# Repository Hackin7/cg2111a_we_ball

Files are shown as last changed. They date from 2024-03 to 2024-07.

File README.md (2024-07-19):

# cg2111a_we_ball

our robot will move as smoothly as a ball. Code here is modified from the template code with our various additions. More information about those additions can be found in our reports in `reports/`

# `main` branch

## PC - Client Code

Code found in `client_pc/tls-client-lib`. Compile using `compile.sh` and run `tls-alex-client <IP> <PORT>`.

# `main-rpi` branch

Repository should be put in `/home/pi/Documents/cg2111a_we_ball/`

## Arduino - Firmware Code

Code can be found in `/arduino/Alex`

For the `.ino` files, the compiler first loads the principal file (the one with the same name as the folder)
and then loads the others in alphabetical order. Concept behind multiple files can be found here: 
https://forum.arduino.cc/t/correct-way-to-include-multiple-files/507705/3 

Order of imports would be as such (think of it as combining into 1 big `.ino` file in this order)

```
Alex.ino
0_motors.ino
...
6_robotlib.ino
```

To get it to compile make sure to import `serialize.zip` as an arduino library first.

The compile and upload script for the firmware is in `arduino/upload.sh`

## RPi - Server Code

Can run  `server_rpi/start.sh`

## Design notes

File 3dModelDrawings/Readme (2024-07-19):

Just a compilation of the chassis 3d models

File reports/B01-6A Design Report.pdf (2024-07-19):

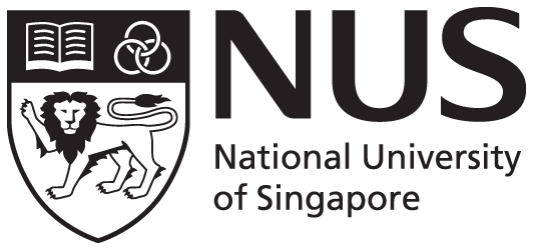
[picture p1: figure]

### CG2111A Engineering Principle and Practice II

Semester 2 2022/2023

## “Alex to the Rescue”

# Design Report Team: B01-6A

Name | Student # | Sub-Team | Role
Jonathan Ong | A0283070L | Software | Colour Detection/ Hardware Design
Quan Teng Wai | A0281416H | Software | LIDAR Implementation
Piraveen Alexander | A0273022U | Software | Robot Movement
Chan Zun Mun Terence | A0282142M | Hardware | Circuit Design
1 | Page

Section 1 System Functionalities

Our Alex Robot is designed to emulate the functionalities of a search and rescue robotic vehicle. It would be wirelessly controlled by operators to move in a simulated environment.

Alex will include a Raspberry Pi and an Arduino Mega. The Raspberry Pi has a Master Control Program to communicate with Arduino via UART. The Arduino is then able to control the motors and return information from the ultrasonic sensors to the Raspberry Pi, for Alex to gather data and navigate through the Course. At the same time, the Raspberry Pi receives data from the LIDAR to map out the environment.

The operators would use a Laptop. It communicates with the Raspberry Pi to remotely control the robot, using SSH for controlling movement & sensors, and ROS Networking for retrieving SLAM data.

Simulated Environment
Our Alex would be used in a room with various objects, such as tables, chairs and boxes. We would pilot Alex to find at least 2 victims in a 6-minute window. These victims are green (healthy but trapped), or red (injured and trapped).

Main Functionalities:
1. Move orthogonally (Forwards, Backwards, Left Turn, Right Turn)
2. Identify objects within the test area using the Colour Sensor
3. Map out the test area with the help of the LIDAR and SLAM
4. Enough battery life to minimally last the entire test duration ( ~15min )
5. Be remote-controlled by a teleoperator

Additional Functionalities:
1. Detect the colour of any nearby object.
2. Alex is able to be “cool”
a. It would have Ultrasonic Sensors to detect the distance of the front/ back/ side of the robot to the obstacles
b. It would have a face (our teammate’s)

Section 2 Review of State of the Art

There are many different designs in the modern search and rescue robotic arsenal. Here are 2 that interested us.
1. Earthshaker, winner of the first Advanced Technology and Engineering Challenge (A-TEC) championships.

Teleoperation was achieved with 3 different communication methods between the Operator PC and the On-board computer (NUC).
Using a 1.8G MIMO mesh radio, 2xAT9S, STM32 Control board and a 4G/5G router.
Software enables automated switching

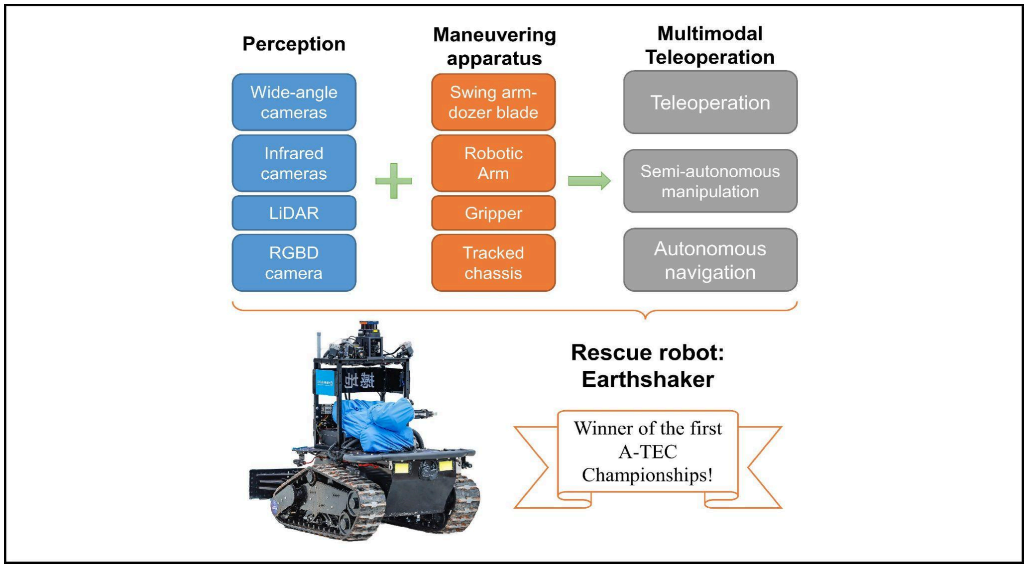
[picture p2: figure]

between communication modes depending on connection quality/ range.

Strengths | Weaknesses
- Chassis and components minimally IP64 water resistant, able to handle wet environments ● Dozer Blade allows it to push obstacles under 75kg away ● Multiple communication methods, from 2.4Ghz direct communication to 1.8 GHz MIMO-mesh radios to suit a different ranges and conditions | ● Excessive size limited flexibility of movement ● Lacking in gripping power for modified robot arm, unable to manipulate heavier loads. ● Battery life of 3h ● Cumbersome body slower at navigating stairs
2. Vapor 55 Drone, used in spotting sharks, dropping life rafts and medical equipment in Australia, originally designed to deliver blood and supplies to wounded soldiers.

Hardware:
Trillium HD-25 Optical sensor (Camera) Lidar/ PPK Mapping Options

Software:
Advanced Flight Control System (FCS) [inclusive of autopilot]
Automatic Autorotation, smart auto-home functions

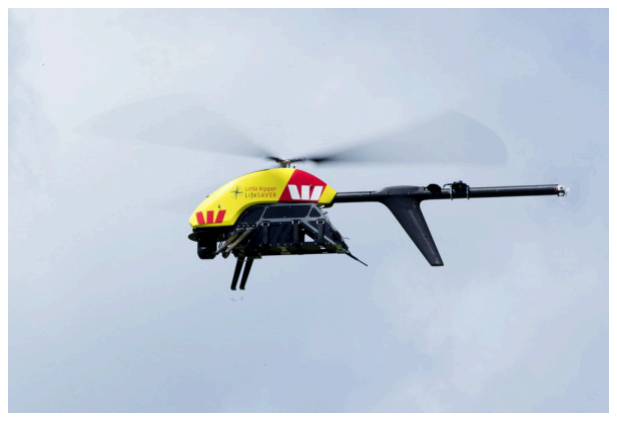
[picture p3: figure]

Strengths | Weaknesses
- Modular radio options (Common Radio Interface connector) ● Flexible Payload - rail design enables many different kinds of payloads to be equipped ● Aerial - Unrestricted by Terrain | ● Battery life of 1h ● Environmental Operational Limits from -17C to 49C, unable to be used in extreme temperatures ● Comparatively low Usable payload of 4.5kg compared to ground options

(Rubble/ Ocean)

Section 3 System Architecture High Level Components

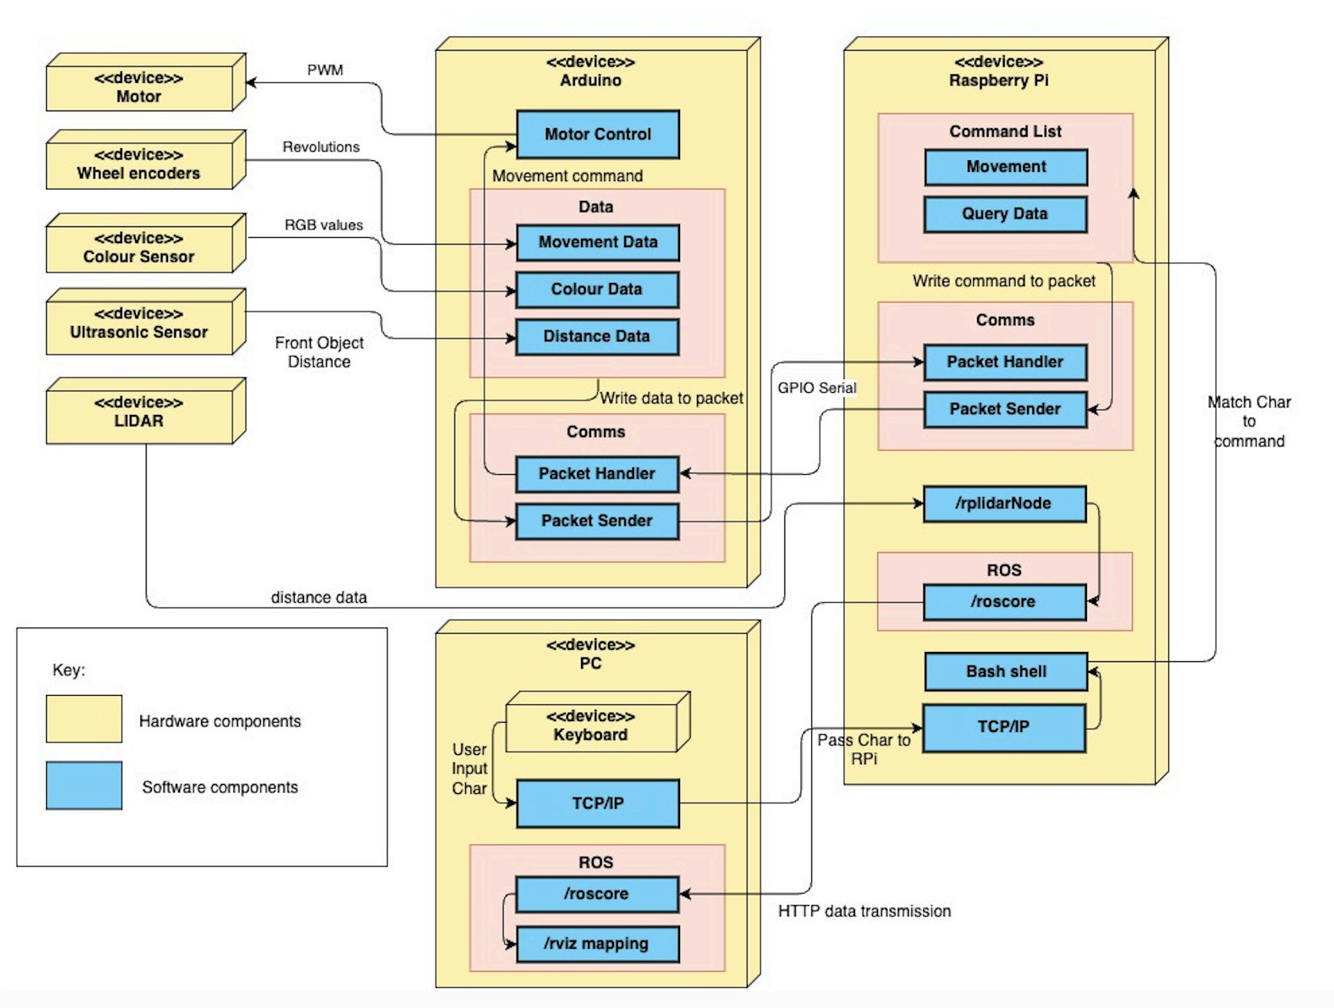
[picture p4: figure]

Schematic (Subject to Changes)

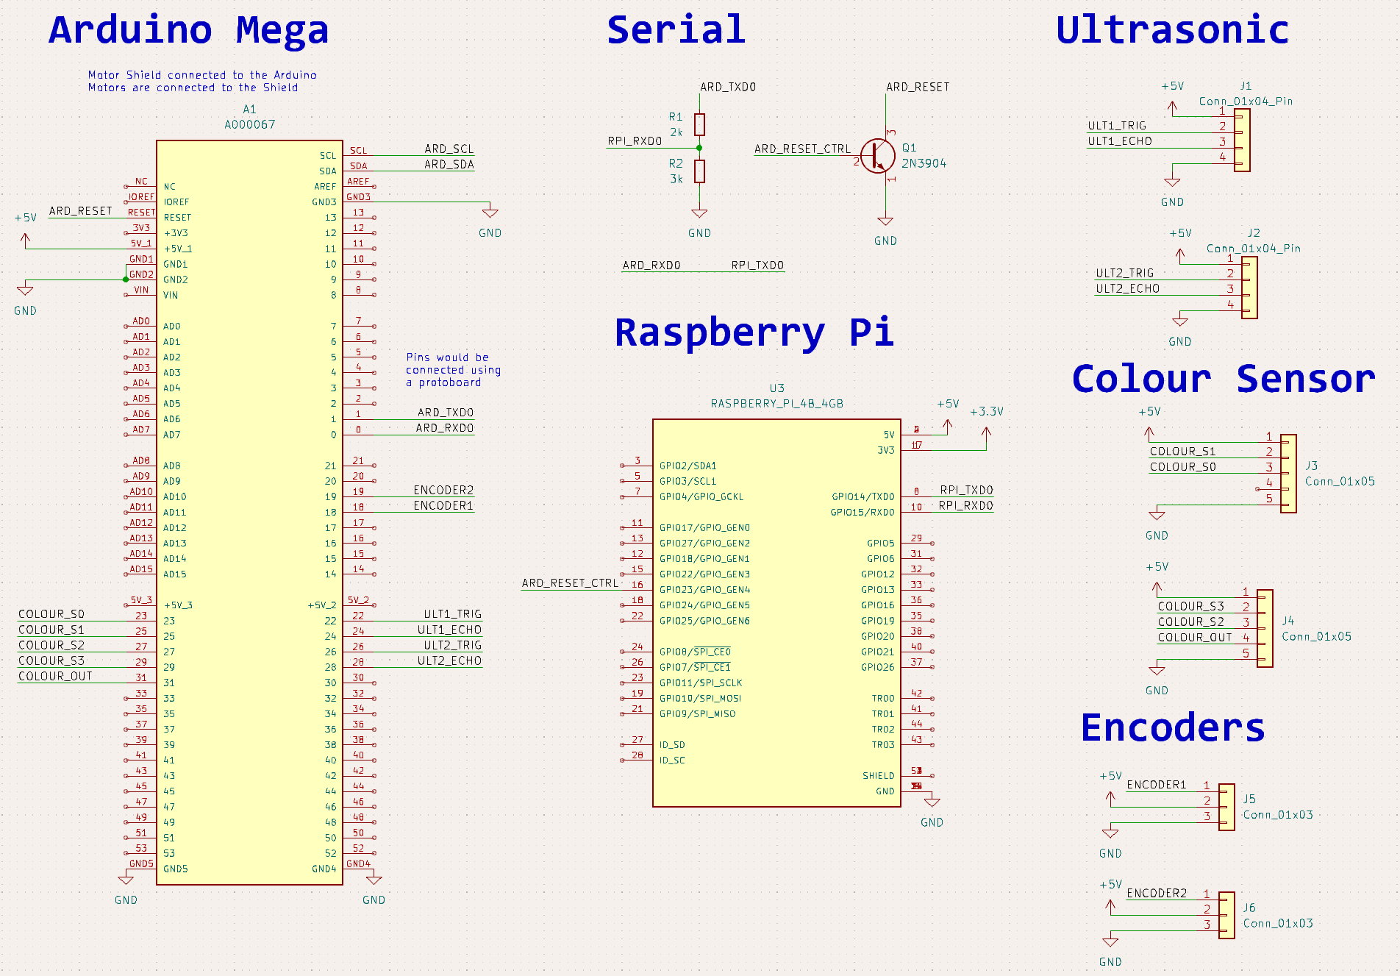
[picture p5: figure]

Electronics will be connected through wires and a protoboard for ease of assembly, and ease of access to the pins.

1. LIDAR would be connected to the Raspberry Pi via USB
2. Motors would be connected to the Motor Shield, and the Motor Shield would be connected to the Arduino. The Protoboard goes between the Shield and the Arduino
3. The RPi would be powered by a USB Power Bank, while the Motors and Motor Shield will be powered by 4 1.5V AA batteries

Section 4 Component Design

High-Level Algorithm Steps:
1. Initialise communication between Arduino, Pi and PC
2. Generate map with Hector SLAM
3. Receive tele-operator commands
4. Carry out commands
5. Repeat steps 3 and 4 until navigation is over

Further Breakdown
Step 1: Initialise communication between Arduino, Pi and PC
a. Pi - Arduino Mega Communication
i. Pi opens a Serial Connection to the Arduino Mega
ii. | Pi creates, serializes and sends a Hello Packet to the Arduino
iii. | Arduino initialises the Serial port and responds to the Hello Packet by sending
| back an OK packet
b. Pi - Laptop Communications
i. Pi opens a TCP/IP server and binds to a port
ii. | The laptop connects to the server over the same WiFi Network
iii. | With the help of OpenSSL, the Laptop authenticates with the Pi and
| communicates securely.
c. Others
i. ROS is Started on the Pi, which the Laptop connects to through ROS
| networking
ii. | The Laptop can SSH/ VNC into the Pi
Step 2: Generate map with Hector SLAM
a. Pi gets distance data from LIDAR and odometry data from Arduino
b. Pi sends occupancy data to PC through ROS
c. PC generates map with Hector SLAM with occupancy data
Step 3: Receive tele-operator commands
a. After reviewing map, tele-operator sends commands:
| Movement Commands
W | A | S | D | X
Forward (increase linear speed in positive direction) | Rotate Left (increase angular speed in negative direction) | Stop | Rotate Right (increase angular speed in positive direction) | Reverse (increase linear speed in negative direction)

Additional Commands

C V

Sense colour | Get ultrasonic sensor distance
b. PC sends commands to Pi through TCP/IP through the packet sender
c. Pi handles packets and sends commands to Arduino

Step 4: Carry out commands
a. Depending on the command, Arduino does the following:
Command Type | Movement | Colour | Ultrasonic Sensor
Execution | sends PWM signals to motors | triggers colour sensor | triggers ultrasonic sensor
Return | odometry data calculated from wheel encoders | colour determined from RGB values | returns ultrasonic distance
b. Pi receives the data from the Arduino and LIDAR and handles it as follows:
Arduino | LIDAR
Colour | Ultrasonic Sensor | Map data
Returns data to PC through TCP/IP | | Publishes to ROS topic
c. PC receives data and does the following:
TCP/IP data | ROS data
displays to tele-operator | updates Hector SLAM map and displays to tele-operator
Step 5: Repeat steps 3 and 4 until navigation is over
a. Tele-operator identifies when navigation is over and sends command to end program

Serial Communications
Raspberry Pi
1. Pi opens a Serial Connection to the Arduino Mega
a. Baud Rate 9600 bps, 8N1 Frame format
2. Pi creates a receiver thread to receive packets from Arduino
a. The packet is deserialized into a TPacket packet, and TResult result
b. It checks TResult for the status of the packet
i. If the Packet received is OK, it handles it (such as in Further Breakdown Step 4b)
ii. | Else, it displays the error, be it an unknown error, bad magic number,
| or bad checksum, and sends it to the laptop
3. Pi Sends command packets to the Arduino depending on the teleoperator commands
a. It creates a TPacket commandPacket
b. Configures the packet command and parameters c. Serialises it into a TComms packet
d. Sends it over to the Arduino through UART

Arduino Mega
4. Arduino Mega sets up Serial port
a. Baud Rate 9600 bps, 8N1 Frame format
5. Arduino polls for serial data
a. It reads the Serial data & stores it in a buffer
b. The data is then deserialized into a TPacket packet and TResult result
c. It checks TResult result for the status of the packet
i. If the Packet received is OK,
1. it handles it (such as in Further Breakdown Step 4a),
2. It sends an OK packet to the Pi, or a packet with the required information depending on the command.
ii. | Else, it sends an error back to the Pi, be it an unknown error, bad magic
| number, or bad checksum
iii. | The creation of packets is similar to how the Raspberry Pi does it

Distance Sensing Algorithm
1. Set the trigger pin to high for 10 microseconds to send the pulse
2. Reads the Echo Pin and gets the length of the pulse on the echo pin
3. Convert the period to the distance between the ultrasonic sensor to the wall
a. Distance = (Speed of Sound × Time taken) / 2
4. Sends a packet with the distance information to the RPi

Color Sensing Algorithm
1. Set Trigger pin to HIGH to trigger Colour Sensing
2. Colour Sensor Module to cycle between RGB lighting
a. Individually Toggle Each of the colour LED Pins to HIGH, delay, then LOW.
b. Read the respective frequencies from the colour sensor during each colour phase
3. With reference to the ROYGBIV table that has the respective range of frequencies for each colour, determine the colour of the object in front of the Color Sensor.
4. Relay information to the RPi, which is then sent to the laptop.

Section 5 Project Plan

Week | Hardware | Software
8 & 9 | Assembling Alex & Electronics | 1. Communications between Arduino & Raspberry Pi 2. Configure Motor Encoders 3. Set up Secure Communications (TLS)
10 | 1. Finalise Electronics Schematic & Wiring the Protoboard 2. Debugging the Protoboard & Electronics | Setting up the Raspberry Pi 1. SSH, VNC remote protocols for Debugging 2. Code Repository & Layout
11 | 1. Mounting of Components 2. Designing and 3D printing required structures | 1. Setting up Hector SLAM 2. Setting up Colour Sensor & Colour Detection Algorithm 3. Test Basic Movement
12 | 1. Adjusting Mounts | 1. Setting up Ultrasonic Sensor 2. Calibration of Motors, Ultrasonic Sensors and Colour Sensors
13 | 1. Final Calibration & Further improvements based on trial run 2. Project Runs
Reading Week | Final Design Report

References

1. Zhang Y, Li Y X, Zhang H F, et al.
Earthshaker: A mobile rescue robot for emergencies and disasters through teleoperation and autonomous navigation.
JUSTC, 2023, 53(1): 4 doi: 10.52396/JUSTC-2022-0066
2. Avinc (n.d.) Product catalog. Retrieved March 28, 2024, from https://www.avinc.com/images/uploads/product_docs/ProductCatalog.pdf
3. Avnic (August 30, 2019). Vapor55 Datasheet. Retrieved March 28, 2024, from, https://www.avinc.com/images/uploads/product_docs/VAPOR55_datasheet_0830201 9.pdf (https://www.avinc.com/images/uploads/product_docs/VAPOR55_datasheet_08302019.pdf)
4. Little Ripper (n.d.) Our Amazingly Awesome & Proven UAV Fleet: Westpac Lifesaver Series. Retrieved March 28, 2024, from,
https://littleripper.com/our-fleet/

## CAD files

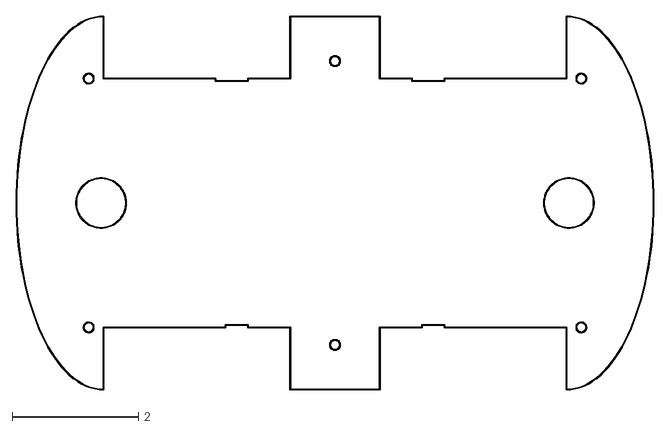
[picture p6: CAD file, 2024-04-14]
hardware/cg2111a_robot_kicad/cg2111a_robot-Edge_Cuts.dxf
10.1 x 5.92

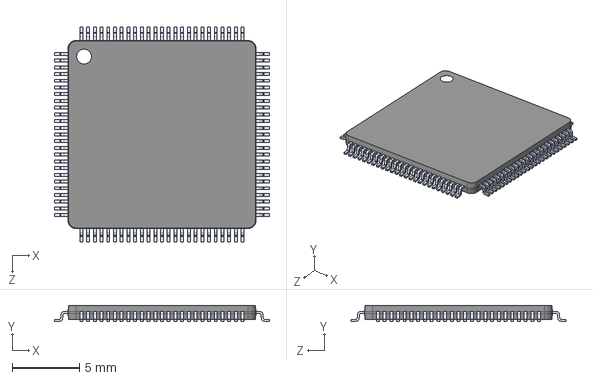
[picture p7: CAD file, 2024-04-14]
hardware/cg2111a_robot_kicad/footprints/3d_models/ATMEGA2560-16AU.step
16.0 x 1.20 x 16.0 mm

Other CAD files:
3dModelDrawings/002 v2.f3d
3dModelDrawings/Back Board v1.f3d
3dModelDrawings/Nozzle v1.f3d
3dModelDrawings/Potoboard holder v5.f3d
3dModelDrawings/Side Plate v1.f3d
3dModelDrawings/TANK v2.f3z

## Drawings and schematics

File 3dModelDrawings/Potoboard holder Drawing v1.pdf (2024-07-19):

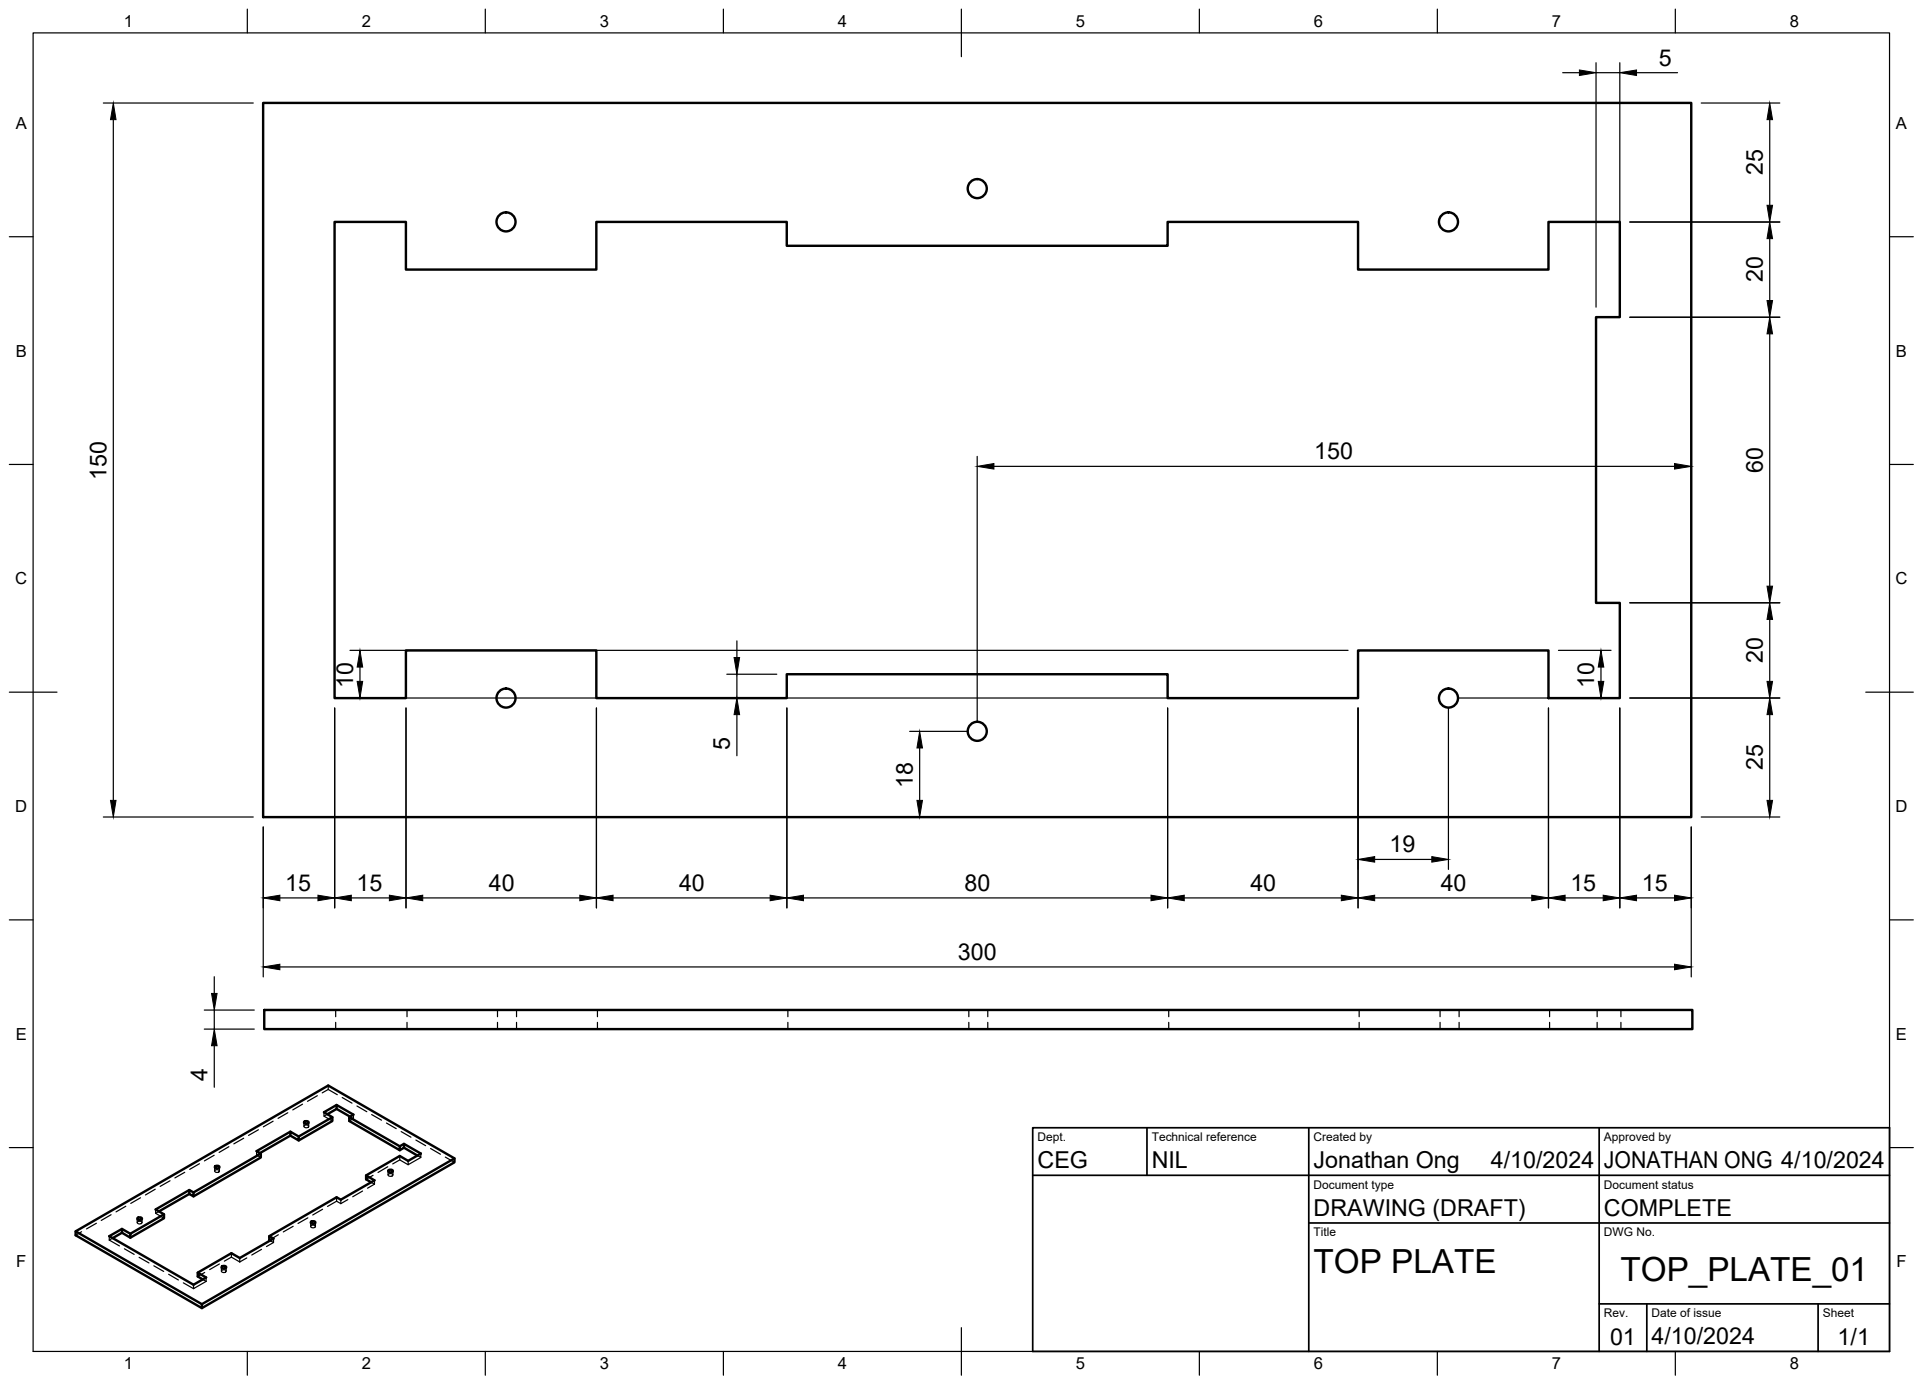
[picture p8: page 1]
Title; DWG No.; Rev.; Date of issue; Sheet; TOP PLATE; TOP_PLATE_01; CEG; NIL; Jonathan Ong; JONATHAN ONG 150

Dept. | Technical reference | Created by 4/10/2024 | Approved by 4/10/2024

Document type DRAWING (DRAFT) | Document status COMPLETE

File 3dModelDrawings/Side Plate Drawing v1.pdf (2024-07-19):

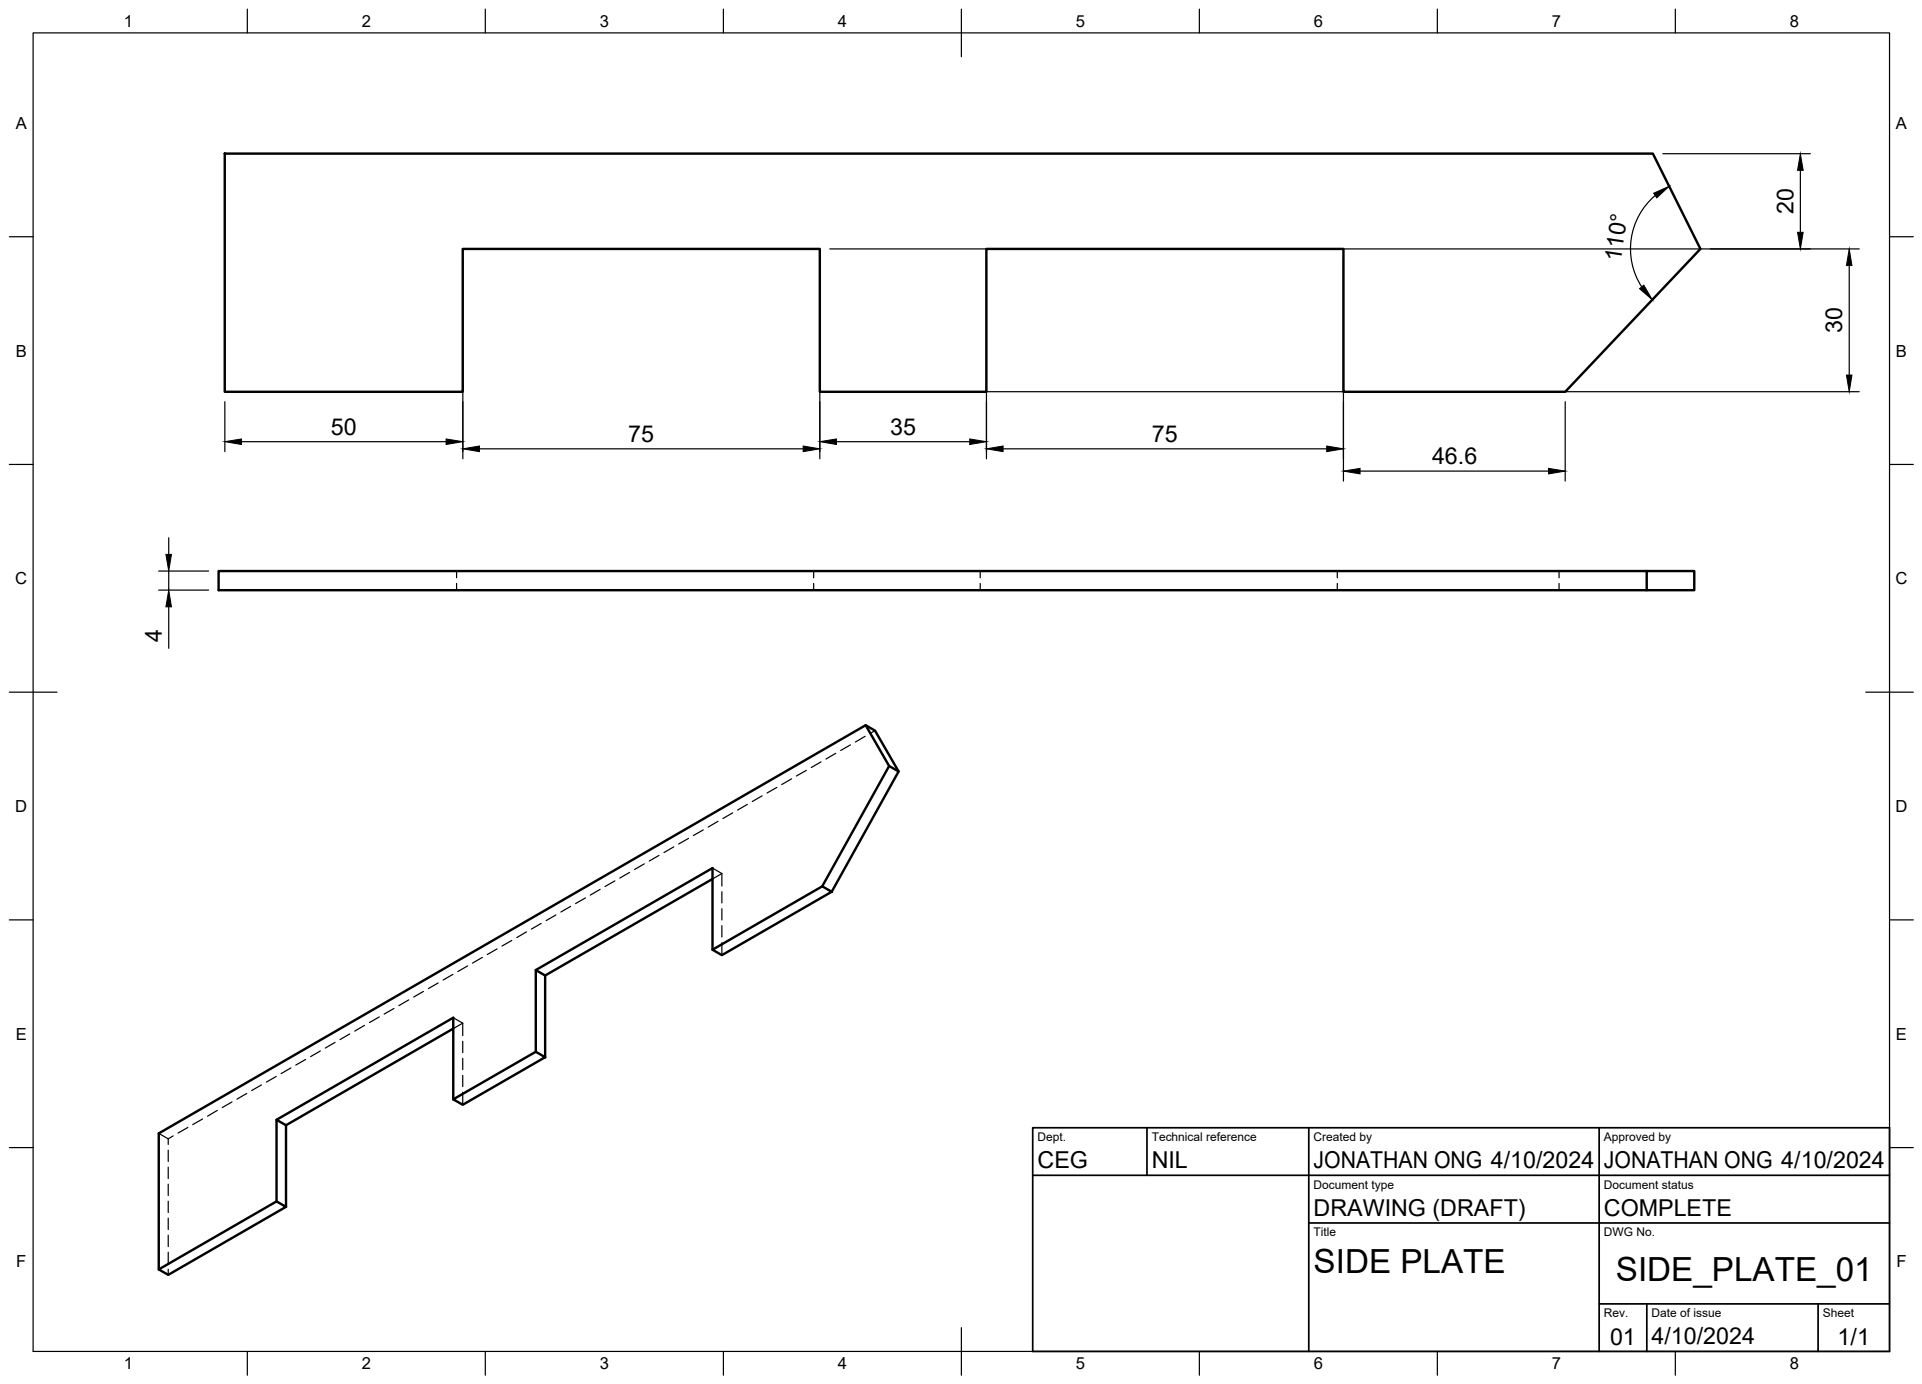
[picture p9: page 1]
Title; DWG No.; Rev.; Date of issue; Sheet; SIDE PLATE; SIDE_PLATE_01

Dept. CEG | Technical reference NIL | Created by JONATHAN ONG 4/10/2024 | Approved by JONATHAN ONG 4/10/2024

Document type DRAWING (DRAFT) | Document status COMPLETE

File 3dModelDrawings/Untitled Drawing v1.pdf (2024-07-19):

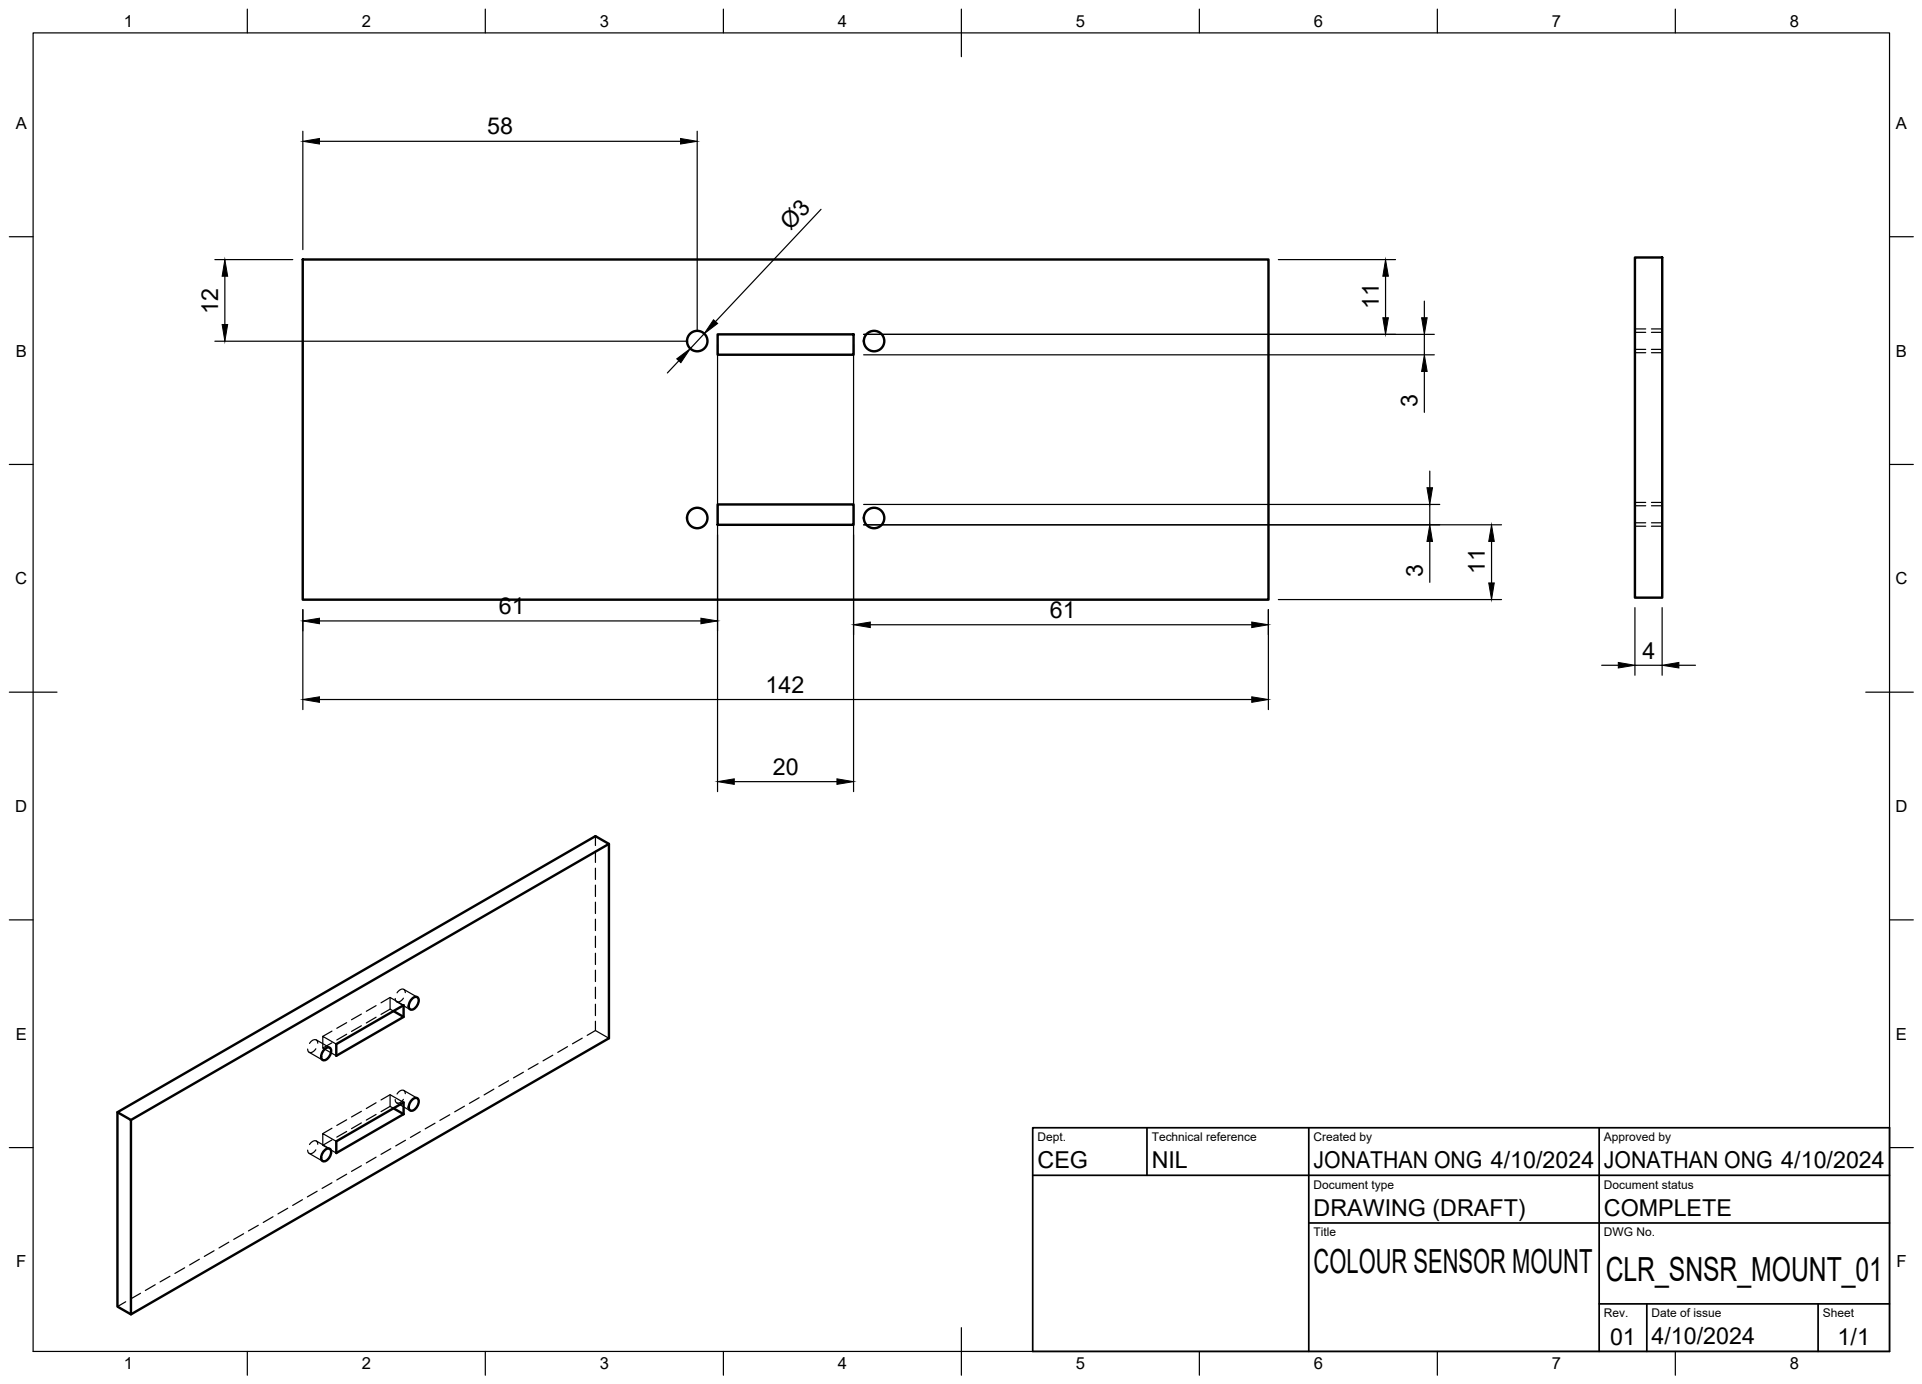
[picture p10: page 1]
Title; DWG No.; Rev.; Date of issue; Sheet; COLOUR SENSOR MOUNT; CLR_SNSR_MOUNT_01

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

Document type DRAWING (DRAFT) | Document status COMPLETE

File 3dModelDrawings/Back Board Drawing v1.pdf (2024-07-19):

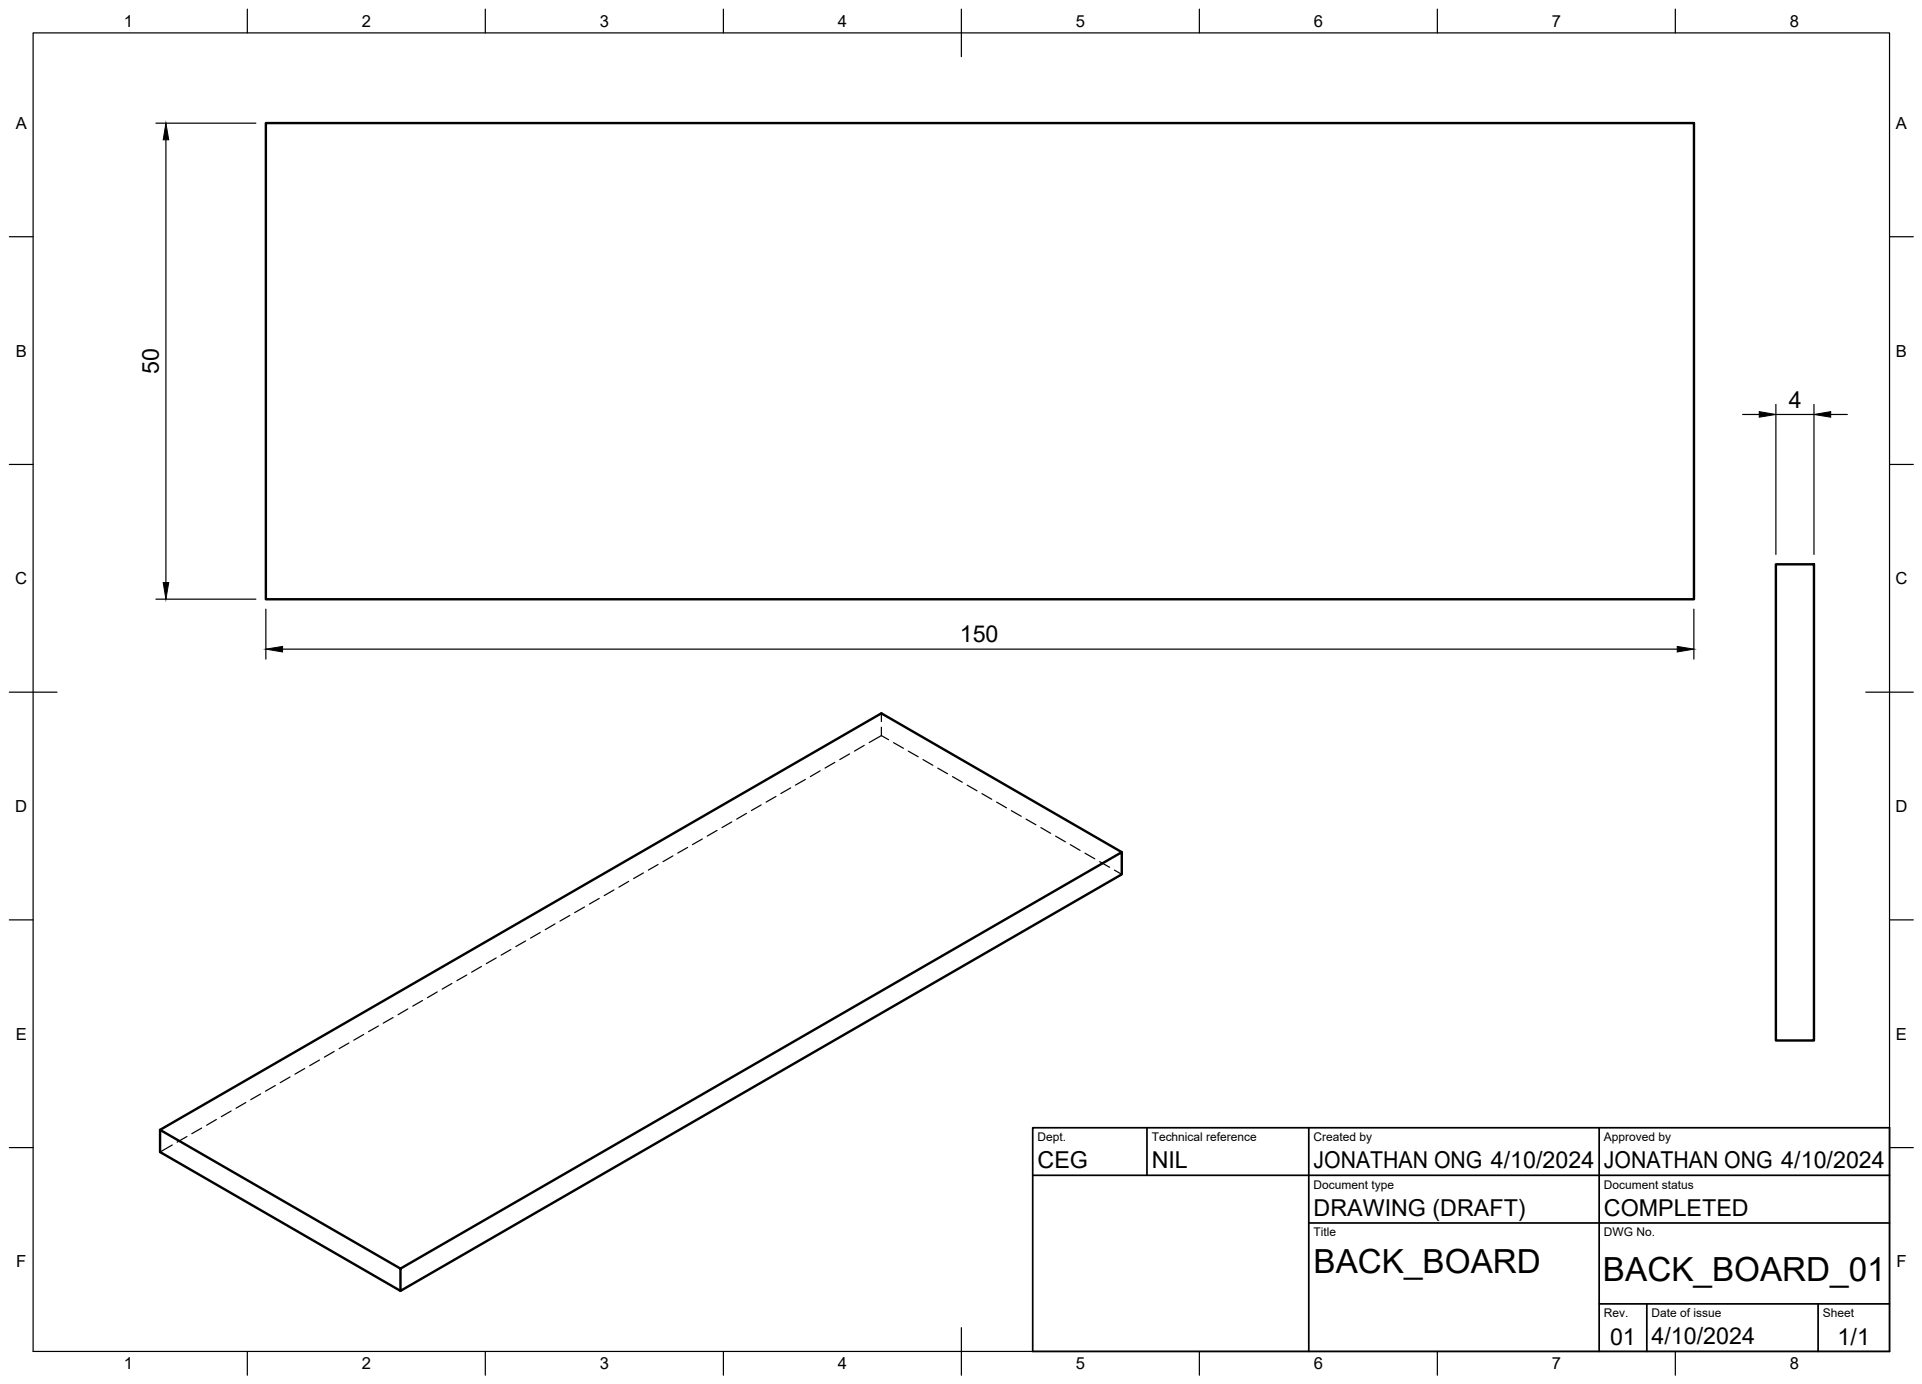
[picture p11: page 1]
Title; DWG No.; Rev.; Date of issue; Sheet; CEG; NIL; JONATHAN ONG; JONATHAN ONG 50

Dept. | Technical reference | Created by 4/10/2024 | Approved by 4/10/2024

Document type DRAWING (DRAFT) | Document status COMPLETED

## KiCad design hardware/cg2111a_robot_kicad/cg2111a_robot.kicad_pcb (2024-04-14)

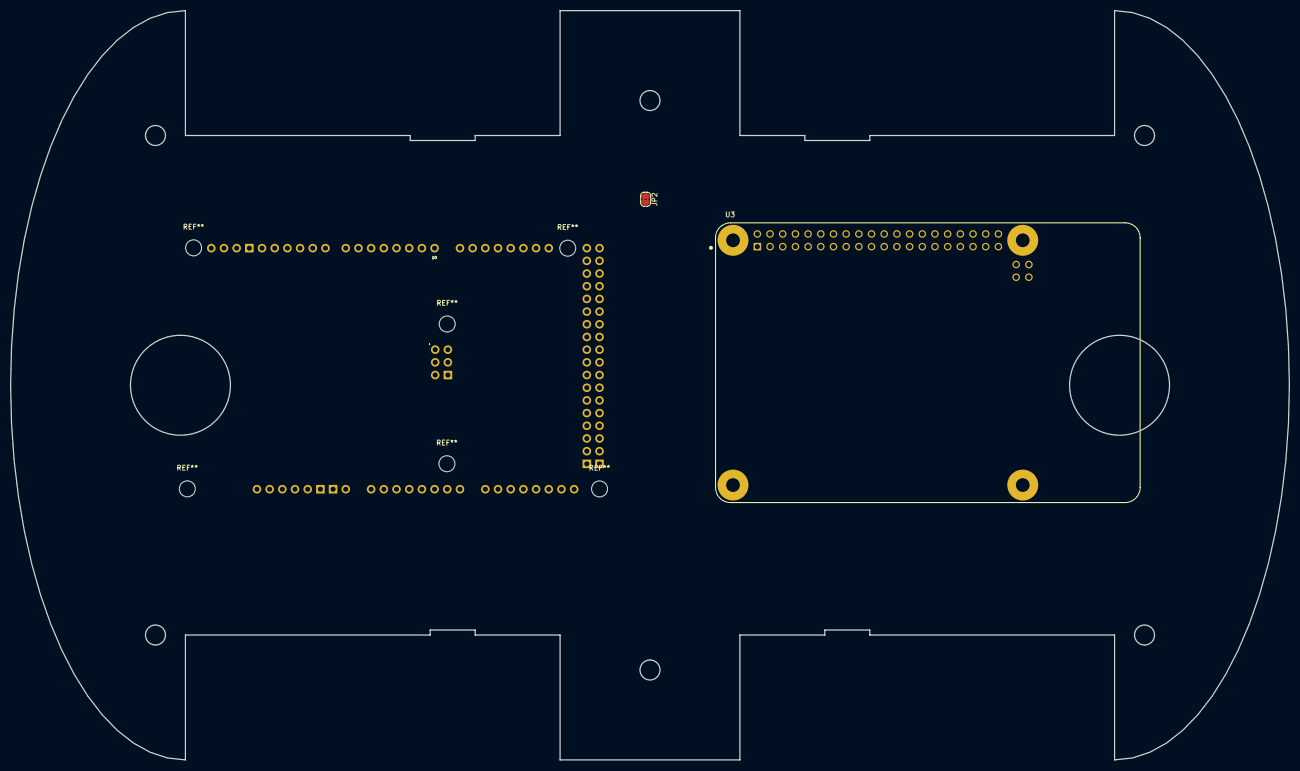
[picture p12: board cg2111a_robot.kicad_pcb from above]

Board: 2 copper layers, 256.0 x 150.0 mm, 3 parts (0 on the bottom side), 4 nets, no tracks yet.

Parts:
JP2: SolderJumper_2_Bridged; SolderJumper-2_P1.3mm_Bridged2Bar_RoundedPad1.0x1.5mm
U3: RASPBERRY_PI_4B_4GB; MODULE_RASPBERRY_PI_4B_4GB
XA1: Arduino_Mega2560_Shield

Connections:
GND: U3.6 (GND), U3.9 (GND), U3.14 (GND), U3.20 (GND), U3.25 (GND), U3.30 (GND), U3.34 (GND), U3.39 (GND)
unnamed: U3.2 (5V), U3.4 (5V)
unnamed: U3.S1 (SHIELD), U3.S2 (SHIELD), U3.S3 (SHIELD), U3.S4 (SHIELD)
VCC: JP2.1 (A), U3.1 (3V3), U3.17 (3V3)

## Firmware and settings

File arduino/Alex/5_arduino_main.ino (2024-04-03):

void setup() {
  // put your setup code here, to run once:
  alexDiagonal = sqrt((ALEX_LENGTH * ALEX_LENGTH) + (ALEX_BREADTH *
    ALEX_BREADTH));
  alexCirc = PI * alexDiagonal;
  
  cli();
  setupEINT();
  setupSerial();
  startSerial();
  enablePullups();
  initializeState();
  sei();
}



void loop() {

  //motorDebug();
  // put your main code here, to run repeatedly:
  TPacket recvPacket; // This holds commands from the Pi

  TResult result = readPacket(&recvPacket);
  
  if(result == PACKET_OK){
      handleCommand(&recvPacket);
  }else{
    if(result == PACKET_BAD)
    {
      sendBadPacket();
    }
    else if(result == PACKET_CHECKSUM_BAD)
    {
      sendBadChecksum();
    } 
  }

  if(deltaDist > 0)
  {
    if(dir==FORWARD)
    {
      if(forwardDist > newDist)
      {
        deltaDist=0;
        newDist=0;
        stop();
      }
    } else if (dir == BACKWARD)
    {
      if(reverseDist > newDist)
      {
      deltaDist=0;
      newDist=0;
      stop();
      }
    } else if(dir == STOP)
    {
      deltaDist=0;
      newDist=0;
      stop();
    }
  }
    
  if (deltaTicks > 0) {
    if (dir == LEFT) {
      if (leftReverseTicksTurns >= targetTicks){
        dbprintf("reset1: %d %d", leftReverseTicksTurns, targetTicks, "\n");
        deltaTicks = 0;
        targetTicks = 0;
        stop();
      }
    } else if (dir == RIGHT) {
      if (rightReverseTicksTurns >= targetTicks){
        dbprintf("reset2: %d %d", rightReverseTicksTurns, targetTicks, "\n");
        deltaTicks = 0;
        targetTicks = 0;
        stop();
      } 
    } else if (dir == STOP) {
        dbprintf("reset3: %d", targetTicks, "\n");
      deltaTicks = 0;
      targetTicks = 0;
      stop();
    } 
  }    
      
}

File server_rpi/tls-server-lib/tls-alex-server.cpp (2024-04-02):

#include "make_tls_server.h"
#include "tls_common_lib.h"
#include "netconstants.h"
#include "constants.h"
#include "packet.h"
#include "serial.h"
#include "serialize.h"

/* TODO: Set PORT_NAME to the port name of your Arduino */
#define PORT_NAME			"/dev/ttyS0"
/* END TODO */

// Check and ensure that this baud rate is the same
// as what is used in Alex.ino
#define BAUD_RATE			B9600

// TLS Port Number
#define SERVER_PORT			5001

/* TODO: #define constants for the  filenames for Alex's private key, certificate, CA certificate name,
        and the Common Name for your laptop */


#define PORTNUM 5001
#define KEY_FNAME   "keys/alex.key"
#define CERT_FNAME  "keys/alex.crt"
#define CA_CERT_FNAME   "keys/signing.pem"
#define CLIENT_NAME     "laptop.cg2111a.we.ball.com"
/* END TODO */

// Our network buffer consists of 1 byte of packet type, and 128 bytes of data
#define BUF_LEN				129

// This variable shows whether a network connection is active
// We will also use this variable to prevent the server from serving
// more than one connection, to keep connection management simple.

static volatile int networkActive;

// This variable is used by sendNetworkData to send back responses
// to the TLS connection.  It is sent by handleNetworkData

static void *tls_conn = NULL;

/*

	Alex Serial Routines to the Arduino

	*/

// Prototype for sendNetworkData
void sendNetworkData(const char *, int);

void handleErrorResponse(TPacket *packet)
{
	printf("UART ERROR: %d\n", packet->command);
	char buffer[2];
	buffer[0] = NET_ERROR_PACKET;
	buffer[1] = packet->command;
	sendNetworkData(buffer, sizeof(buffer));
}

void handleMessage(TPacket *packet)
{
	char data[33];
	printf("UART MESSAGE PACKET: %s\n", packet->data);
	data[0] = NET_MESSAGE_PACKET;
	memcpy(&data[1], packet->data, sizeof(packet->data));
	sendNetworkData(data, sizeof(data));
}

void handleStatus(TPacket *packet)
{
	char data[65];
	printf("UART STATUS PACKET\n");
	data[0] = NET_STATUS_PACKET;
	memcpy(&data[1], packet->params, sizeof(packet->params));
	sendNetworkData(data, sizeof(data));
}

void handleResponse(TPacket *packet)
{
	// The response code is stored in command
	switch(packet->command)
	{
		case RESP_OK:
			char resp[2];
			printf("Command OK\n");
			resp[0] = NET_ERROR_PACKET;
			resp[1] = RESP_OK;
			sendNetworkData(resp, sizeof(resp));
		break;

		case RESP_STATUS:
			handleStatus(packet);
		break;

		default:
		printf("Boo\n");
	}
}


void handleUARTPacket(TPacket *packet)
{
	switch(packet->packetType)
	{
		case PACKET_TYPE_COMMAND:
				// Only we send command packets, so ignore
			break;

		case PACKET_TYPE_RESPONSE:
				handleResponse(packet);
			break;

		case PACKET_TYPE_ERROR:
				handleErrorResponse(packet);
			break;

		case PACKET_TYPE_MESSAGE:
				handleMessage(packet);
			break;
	}
}


void uartSendPacket(TPacket *packet)
{
	char buffer[PACKET_SIZE];
	int len = serialize(buffer, packet, sizeof(TPacket));

	serialWrite(buffer, len);
}

void handleError(TResult error)
{
	switch(error)
	{
		case PACKET_BAD:
			printf("ERROR: Bad Magic Number\n");
			break;

		case PACKET_CHECKSUM_BAD:
			printf("ERROR: Bad checksum\n");
			break;

		default:
			printf("ERROR: UNKNOWN ERROR\n");
	}
}

void *uartReceiveThread(void *p)
{
	char buffer[PACKET_SIZE];
	int len;
	TPacket packet;
	TResult result;
	int counter=0;

	while(1)
	{
		len = serialRead(buffer);
		counter+=len;
		if(len > 0)
		{
			result = deserialize(buffer, len, &packet);

			if(result == PACKET_OK)
			{
				counter=0;
				handleUARTPacket(&packet);
			}
			else 
				if(result != PACKET_INCOMPLETE)
				{
					printf("PACKET ERROR\n");
					handleError(result);
				} // result
		} // len > 0
	} // while
}

/*

	Alex Network Routines

	*/


void sendNetworkData(const char *data, int len)
{
	// Send only if network is active
	if(networkActive)
	{
        // Use this to store the number of bytes actually written to the TLS connection.
        int c;

		printf("WRITING TO CLIENT\n");
 
        if(tls_conn != NULL) {
            /* TODO: Implement SSL write here to write data to the network. Note that
              handleNetworkData should already have set tls_conn to point to the TLS
              connection we want to write to. */
            c = sslWrite(tls_conn, data, len);
            if(c < 0) {
                perror("Error writing to network: " );
            }
            /* END TODO */
        }

		// Network is still active if we can write more then 0 bytes.
		networkActive = (c > 0);
	}
}

void handleCommand(void *conn, const char *buffer)
{
	// The first byte contains the command
	char cmd = buffer[1];
	uint32_t cmdParam[2];

	// Copy over the parameters.
	memcpy(cmdParam, &buffer[2], sizeof(cmdParam));

	TPacket commandPacket;

	commandPacket.packetType = PACKET_TYPE_COMMAND;
	commandPacket.params[0] = cmdParam[0];
	commandPacket.params[1] = cmdParam[1];

	printf("COMMAND RECEIVED: %c %d %d\n", cmd, cmdParam[0], cmdParam[1]);
	
	switch(cmd)
	{
		case 'f':
		case 'F':
			commandPacket.command = COMMAND_FORWARD;
			uartSendPacket(&commandPacket);
			break;

		case 'b':
		case 'B':
			commandPacket.command = COMMAND_REVERSE;
			uartSendPacket(&commandPacket);
			break;

		case 'l':
		case 'L':
			commandPacket.command = COMMAND_TURN_LEFT;
			uartSendPacket(&commandPacket);
			break;

		case 'r':
		case 'R':
			commandPacket.command = COMMAND_TURN_RIGHT;
			uartSendPacket(&commandPacket);
			break;

		case 's':
		case 'S':
			commandPacket.command = COMMAND_STOP;
			uartSendPacket(&commandPacket);
			break;

		case 'c':
		case 'C':
			commandPacket.command = COMMAND_CLEAR_STATS;
			commandPacket.params[0] = 0;
			uartSendPacket(&commandPacket);
			break;

		case 'g':
		case 'G':
			commandPacket.command = COMMAND_GET_STATS;
			uartSendPacket(&commandPacket);
			break;

		default:
			printf("Bad command\n");

	}
}

void handleNetworkData(void *conn, const char *buffer, int len)
{
    /* Note: A problem with our design is that we actually get data to be written
        to the SSL network from the serial port. I.e. we send a command to the Arduino,
        get back a status, then write to the TLS connection.  So we do a hack:
        we assume that whatever we get back from the Arduino is meant for the most
        recent client, so we just simply store conn, which contains the TLS
        connection, in a global variable called tls_conn */

        tls_conn = conn; // This is used by sendNetworkData

  printf("received network data, %.*s\n",len,buffer);
	if(buffer[0] == NET_COMMAND_PACKET)
		handleCommand(conn, buffer);
}
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

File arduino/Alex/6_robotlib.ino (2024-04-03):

#include <AFMotor.h>

// Motor control
#define FRONT_LEFT   4 // M4 on the driver shield
#define FRONT_RIGHT  1 // M1 on the driver shield
#define BACK_LEFT    3 // M3 on the driver shield
#define BACK_RIGHT   2 // M2 on the driver shield

AF_DCMotor motorFL(FRONT_LEFT);
AF_DCMotor motorFR(FRONT_RIGHT);
AF_DCMotor motorBL(BACK_LEFT);
AF_DCMotor motorBR(BACK_RIGHT);

void motorDebug() {

  int speed_scaled = (100.0/100.0) * 255;
  motorFL.setSpeed(speed_scaled);
  motorFR.setSpeed(speed_scaled);
  motorBL.setSpeed(speed_scaled);
  motorBR.setSpeed(speed_scaled);

	motorFL.run(BACKWARD);
        motorFR.run(FORWARD);
        motorBL.run(FORWARD);
        motorBR.run(BACKWARD);
  while (1) {}
}


void move(float speed, int direction)
{
  int speed_scaled = (speed/100.0) * 255;
  motorFL.setSpeed(speed_scaled);
  motorFR.setSpeed(speed_scaled);
  motorBL.setSpeed(speed_scaled);
  motorBR.setSpeed(speed_scaled);

  switch(direction)
    {
      case BACK:
        motorFL.run(BACKWARD);
        motorFR.run(BACKWARD);
        motorBL.run(FORWARD);
        motorBR.run(FORWARD); 
      break;
      case GO:
        motorFL.run(FORWARD);
        motorFR.run(FORWARD);
        motorBL.run(BACKWARD);
        motorBR.run(BACKWARD); 
      break;
      case CW:
        motorFL.run(BACKWARD);
        motorFR.run(FORWARD);
        motorBL.run(FORWARD);
        motorBR.run(BACKWARD); 
      break;
      case CCW:
        motorFL.run(FORWARD);
        motorFR.run(BACKWARD);
        motorBL.run(BACKWARD);
        motorBR.run(FORWARD); 
      break;
      case STOP:
      default:
        motorFL.run(STOP);
        motorFR.run(STOP);
        motorBL.run(STOP);
        motorBR.run(STOP); 
    }
}

void forward(float dist, float speed)
{
  if(dist > 0) {
      deltaDist = dist;
  } else {
      deltaDist=9999999;
  }
  newDist=forwardDist + deltaDist;
  
  dir = (TDirection) FORWARD;
  move(speed, FORWARD);
}

void backward(float dist, float speed)
{
  if(dist > 0) {
      deltaDist = dist;
  } else {
      deltaDist=9999999;
  }
  newDist=reverseDist + deltaDist;
  
  dir = (TDirection) BACKWARD;
  move(speed, BACKWARD);
}

void ccw(float dist, float speed)
{
  dir = (TDirection) LEFT;
  move(speed, CCW);
}

void cw(float dist, float speed)
{
  dir = (TDirection) RIGHT;
  move(speed, CW);
}

void stop()
{
  move(0, STOP);
}

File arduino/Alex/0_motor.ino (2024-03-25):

unsigned long computeDeltaTicks(float ang)
{
  unsigned long ticks = (unsigned long) ((ang * alexCirc * COUNTS_PER_REV) / (360.0 * WHEEL_CIRC));
  return ticks;
}

void left(float ang, float speed) {
  if(ang == 0) {
      deltaTicks=99999999;
  } else {
      deltaTicks=computeDeltaTicks(ang);
  }
  targetTicks = leftReverseTicksTurns + deltaTicks;
  dbprintf("left targetTicks: %d %d", deltaTicks, targetTicks, "\n");
  
  ccw(ang, speed);
}

void right(float ang, float speed) {
  if(ang == 0) {
      deltaTicks=99999999;
  } else {
      deltaTicks=computeDeltaTicks(ang);
  }
  targetTicks = rightReverseTicksTurns + deltaTicks;
  dbprintf("right targetTicks: %d %d", deltaTicks, targetTicks, "\n");
  
  cw(ang, speed);
}

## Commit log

2024-03-25 chore: separate out arduino code
2024-04-02 fix: tls not reading issue
    [tls-alex-server.cpp]
2024-04-03 feat: motor debug stuff
2024-04-14 hardware + client changes
    [ATMEGA2560-16AU.step, cg2111a_robot-Edge_Cuts.dxf, cg2111a_robot.kicad_pcb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]
2024-04-14 motor basic odom using timers
2024-04-22 final edits for final run
    [cg2111a_robot.kicad_sch]
2024-04-28 updates and stuff
    [cg2111a_robot.kicad_sch]
2024-07-19 Add files via upload
    Just some 3d models of the chassis for ALEX
    [002 v2.f3d, Back Board v1.f3d, Nozzle v1.f3d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]
